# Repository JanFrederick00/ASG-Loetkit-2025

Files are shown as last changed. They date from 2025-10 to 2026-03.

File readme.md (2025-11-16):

# ASG-Loetkit-2025

[Löt-Video](https://www.youtube.com/watch?v=-um5J8tv-0Q)

[Demo-Video](https://www.youtube.com/watch?v=5mWFSo3QfBs)

Dieses Projekt ist eine kleine DMX-leuchte, die 9 LEDs enthält und individuell ansteuern kann.

Es wurde speziell dazu entwickelt, einen Einstieg in das SMD-Löten zu bieten. 
Dazu werden zwei der ICs vorgelötet, der Rest der Komponenten wurden dazu ausgewählt, so einfach wie möglich zu löten zu sein.

## Beschreibung der Schaltung

Das Herzstück des Gerätes ist der CH32V003 Microcontroller. 
Dieser empfängt DMX-Signale entweder von einem USB-Serial chip (FT232RL), oder von einem MAX485-Transciever, der die DMX-Signale übersetzt.
Über einen Schalter kann zwischen den beiden Signalquellen umgeschaltet werden. 

Der Microcontroller liest die gewünschte DMX-Adresse von dem DIP-Schalter aus, und entscheidet basierend auf dem eingestellten Kanal-Modus, welche RGB-Farbwerte die LEDs haben sollen.

Die LEDs sind vom Typ WS2812. Das sind einzeln steuerbare RGB-LEDs die häufig in PCs oder anderen bunt leuchtenden dingen verwendet werden. Alle LEDs werden seriell über einen einzigen Pin am 
Microcontroller angesteuert, und formen eine Kette wo das vorherige LED die Daten an die nächste weitergibt.

Der Microcontroller kann einen kleinen push-schalter auslesen, um durch die Modi durchzuwechseln. Eine kleine rote LED kann dazu verwendet werden um das Vorhandensein eines DMX-Signals zu zeigen.

## Verwendung

### Stromversorgung

Das Gerät wird über den USB-Port mit 5V Strom versorgt. 

### DMX-Signal

Als Signalquelle stehen zwei Möglichkeiten zur Auswahl:

- DMX: Die beiden 3-pin Steckverbinder oben rechts sind die DMX in / out ports. Sie verhalten sich wie die Üblichen 3-pin XLR-buchsen, sind aber kleiner und günstiger. Der Schalter muss dafür in der rechten Stellung sein.
- USB: Wenn der FT232-chip installiert ist, dann kann das Gerät auch an einen Computer direkt angeschlossen werden. Dafür verwenden wir die Software `QLC+`, die diesen Chip nativ unterstützt. Der Schalter muss dafür in der linken Stellung sein.

**Anzeigen des DMX-Signals:**

Wenn der Push-schalter gedrückt ist wärend das Gerät eingesteckt wird, dann blinkt die rote LED D10 kurz, wenn ein neues DMX-Datenpaket empfangen wurde. 

### Auswahl eines Kanal-Moduses

Über einen Klick des Push-schalters wird durch die Kanal-Modi gewechselt. Standardmäßig ist das Gerät im 4-Kanal-Modus. Solange der Knopf gedrückt ist wird ein Muster auf den LEDs gezeigt, der den Modus symbolisiert. 

Die verfügbaren Modi sind wie folgt:

**4-Kanal-Modus**

Klassisches RGB + Dimmer

|Channel|Function|
|---|---|
|1|R|
|2|G|
|3|B|
|4|Dimmer|

**27-Kanal-Modus**

R, G, B für jede der 9 LEDs

|Channel|Function|
|---|---|
|3*n+1|R für Dn|
|3*n+2|G für Dn|
|3*n+3|B für Dn|

(wobei n = 0-8 für die 9 LEDs)

**28-Kanal-Modus**

R, G, B für jede der 9 LEDs, und ein Dimmer der alle gleichzeitig dimmt.

|Channel|Function|
|---|---|
|1|Dimmer|
|3*n+2|R für Dn|
|3*n+3|G für Dn|
|3*n+4|B für Dn|

(wobei n = 0-8 für die 9 LEDs)

**36-Kanal-Modus**

R, G, B und Dimmer für jede der 9 LEDs

|Channel|Function|
|---|---|
|4*n+1|R für Dn|
|4*n+2|G für Dn|
|4*n+3|B für Dn|
|4*n+4|Dimmer für Dn|

**HSV-Modus**

3 Kanäle, die Farbe wird dabei im [HSV-Farbraum](https://de.wikipedia.org/wiki/HSV-Farbraum) eingestellt. Kanal 3 ist dabei Helligkeit, die wie der Dimmer agiert.

|Channel|Function|
|---|---|
|1|Hue (Farbton)|
|2|Saturation (Sättigung)|
|3|Value (Dimmer)|

**3-Kanal-Modus**

Klassisches RGB

|Channel|Function|
|---|---|
|1|R|
|2|G|
|3|B|

### Demo-Modus

Wenn man den Auswahlknopf mehr als 10 sekunden hält, dann wechselt das Gerät in einen eingebauten Demo-Modus.
Alle eingehenden DMX-Signale werden dabei ignoriert.

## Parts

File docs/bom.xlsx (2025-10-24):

Reference | Beschreibung | Wer Lötet? | Link | Kosten/stück | Anzahl | MOQ | Margin | Anzahl benötigt insgesamt | Anzahl (aufgerundet) | Kosten
C1 | Kondensator 100nF 0805 | Freddy | (Stock Freddy) | 0 | 1 | 1 | 0 | 15 | 15 | 0
U1 | Microcontroller CH32V003F4P6 | Freddy | (Stock Freddy) | 0.23 | 1 | 1 | 0 | 15 | 15 | 3.45
U3 | FT232RL | Freddy | (Stock Freddy) | 0 | 1 | 1 | 0 | 15 | 15 | 0
C4, C5, C6, C7, C8, C9, C10, C11, C12, C13, C14, C15 | Kondensator 100nF 1206 | Schüler | https://www.lcsc.com/product-detail/C82601.html | 0.0093 | 12 | 50 | 4 | 240 | 250 | 2.325
U2 | MAX485 | Schüler | https://www.lcsc.com/product-detail/C42428254.html?s_z=n_max485 | 0.0904 | 1 | 5 | 0 | 15 | 15 | 1.356
C2, C3 | Kondensator 22pF 1206 | Schüler | https://www.lcsc.com/product-detail/C377027.html | 0.0087 | 2 | 50 | 1 | 45 | 50 | 0.435
D10 | LED rot 1206 | Schüler | https://www.lcsc.com/product-detail/C3646938.html | 0.0105 | 1 | 50 | 1 | 30 | 50 | 0.525
D1, D2, D3, D4, D5, D6, D7, D8, D9 | RGB-LED WS2812 | Schüler | https://www.lcsc.com/product-detail/C22461793.html?s_z=n_ws2812 | 0.0211 | 9 | 20 | 0 | 135 | 140 | 2.954
Y1 | Quartz 24MHz | Schüler | https://www.lcsc.com/product-detail/C7275046.html | 0.0461 | 1 | 10 | 0 | 15 | 20 | 0.922
C16 | Kondensator Elko THT 220uF 5.0x2.5 | Schüler | (Stock Freddy) | 0 | 1 | 1 | 0 | 15 | 15 | 0
SW1 | Slide Switch DPDT | Schüler | https://www.lcsc.com/product-detail/C22435668.html?s_z=n_dpdt | 0.0372 | 1 | 10 | 0 | 15 | 20 | 0.744
SW2 | DIP-Schalter 9P | Schüler | https://www.lcsc.com/product-detail/C3024975.html | 0.2751 | 1 | 19 | 0 | 15 | 19 | 5.2269
SW3 | Tactile Pushbutton | Schüler | https://www.lcsc.com/product-detail/C42416244.html | 0.0149 | 1 | 50 | 0 | 15 | 50 | 0.745
J1 | USB B | Schüler | https://www.lcsc.com/product-detail/C2962393.html | 0.0861 | 1 | 5 | 0 | 15 | 15 | 1.2915
J2, J3 | JST-XH 3P | Schüler | https://www.lcsc.com/product-detail/C5160912.html | 0.0083 | 2 | 50 | 0 | 30 | 50 | 0.415
 | Platinen | N/A |  | 0.39 | 1 | 20 | 0 | 15 | 20 | 7.8
Anzahl Platinen: |  | 15
 |  |  |  |  |  |  |  |  |  | 28.1894

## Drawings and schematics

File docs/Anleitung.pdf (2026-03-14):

## Gigapixel

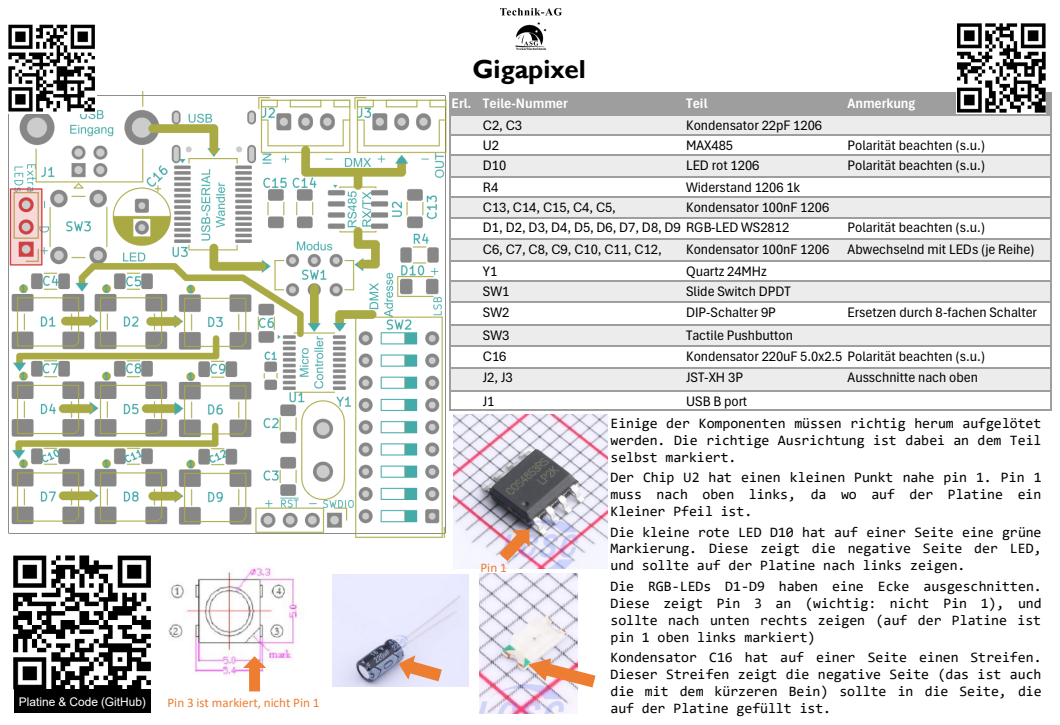
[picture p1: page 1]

Erl. | Teile-Nummer | Teil | Anmerkung
C2, C3 | Kondensator 22pF 1206
U2 | MAX485 | Polarität beachten (s.u.)
D10 | LED rot 1206 | Polarität beachten (s.u.)
R4 | Widerstand 1206 1k
C13, C14, C15, C4, C5, | Kondensator 100nF 1206
D1, D2, D3, D4, D5, D6, D7, D8, D9 RGB-LED WS2812 | | Polarität beachten (s.u.)
C6, C7, C8, C9, C10, C11, C12, | Kondensator 100nF 1206 | Abwechselnd mit LEDs (je Reihe)
Y1 | Quartz 24MHz
SW1 | Slide Switch DPDT
SW2 | DIP-Schalter 9P | Ersetzen durch 8-fachen Schalter
SW3 | Tactile Pushbutton
C16 | Kondensator 220uF 5.0x2.5 Polarität beachten (s.u.)
J2, J3 | JST-XH 3P | Ausschnitte nach oben
J1 | USB B port

Einige der Komponenten müssen richtig herum aufgelötet
werden. Die richtige Ausrichtung ist dabei an dem Teil
selbst markiert.
Der Chip U2 hat einen kleinen Punkt nahe pin 1. Pin 1
muss nach oben links, da wo auf der Platine ein
Kleiner Pfeil ist.
Die kleine rote LED D10 hat auf einer Seite eine grüne
Markierung. Diese zeigt die negative Seite der LED,
und sollte auf der Platine nach links zeigen.
Die RGB-LEDs D1-D9 haben eine Ecke ausgeschnitten.
Diese zeigt Pin 3 an (wichtig: nicht Pin 1), und
sollte nach unten rechts zeigen (auf der Platine ist
pin 1 oben links markiert)
Kondensator C16 hat auf einer Seite einen Streifen.
Dieser Streifen zeigt die negative Seite (das ist auch
die mit dem kürzeren Bein) sollte in die Seite, die

auf der Platine gefüllt ist. Platine & Code (GitHub)

Pin 3 ist markiert, nicht Pin 1

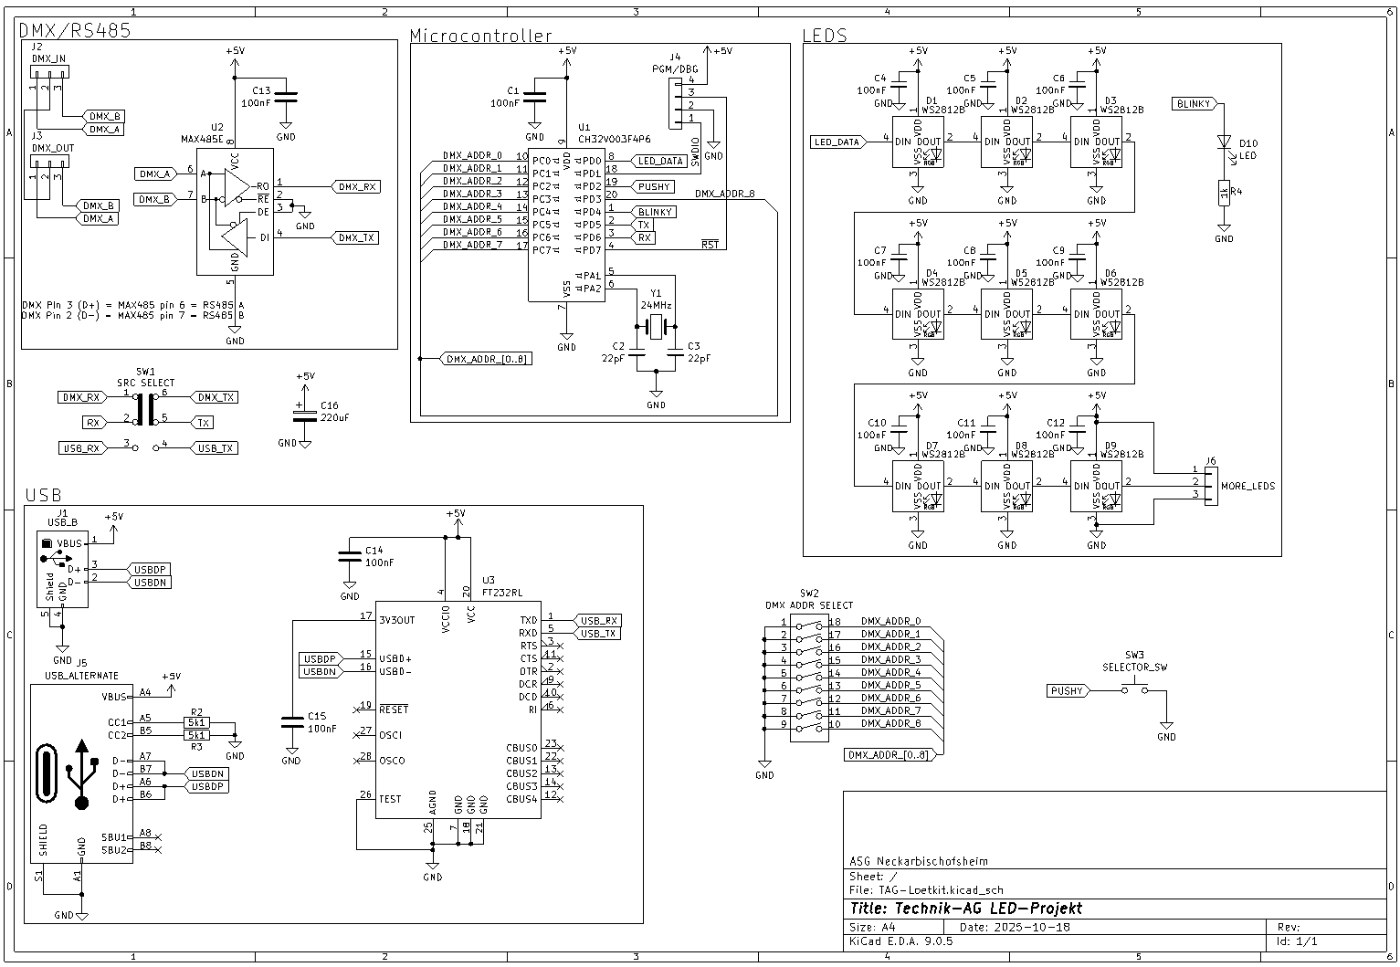
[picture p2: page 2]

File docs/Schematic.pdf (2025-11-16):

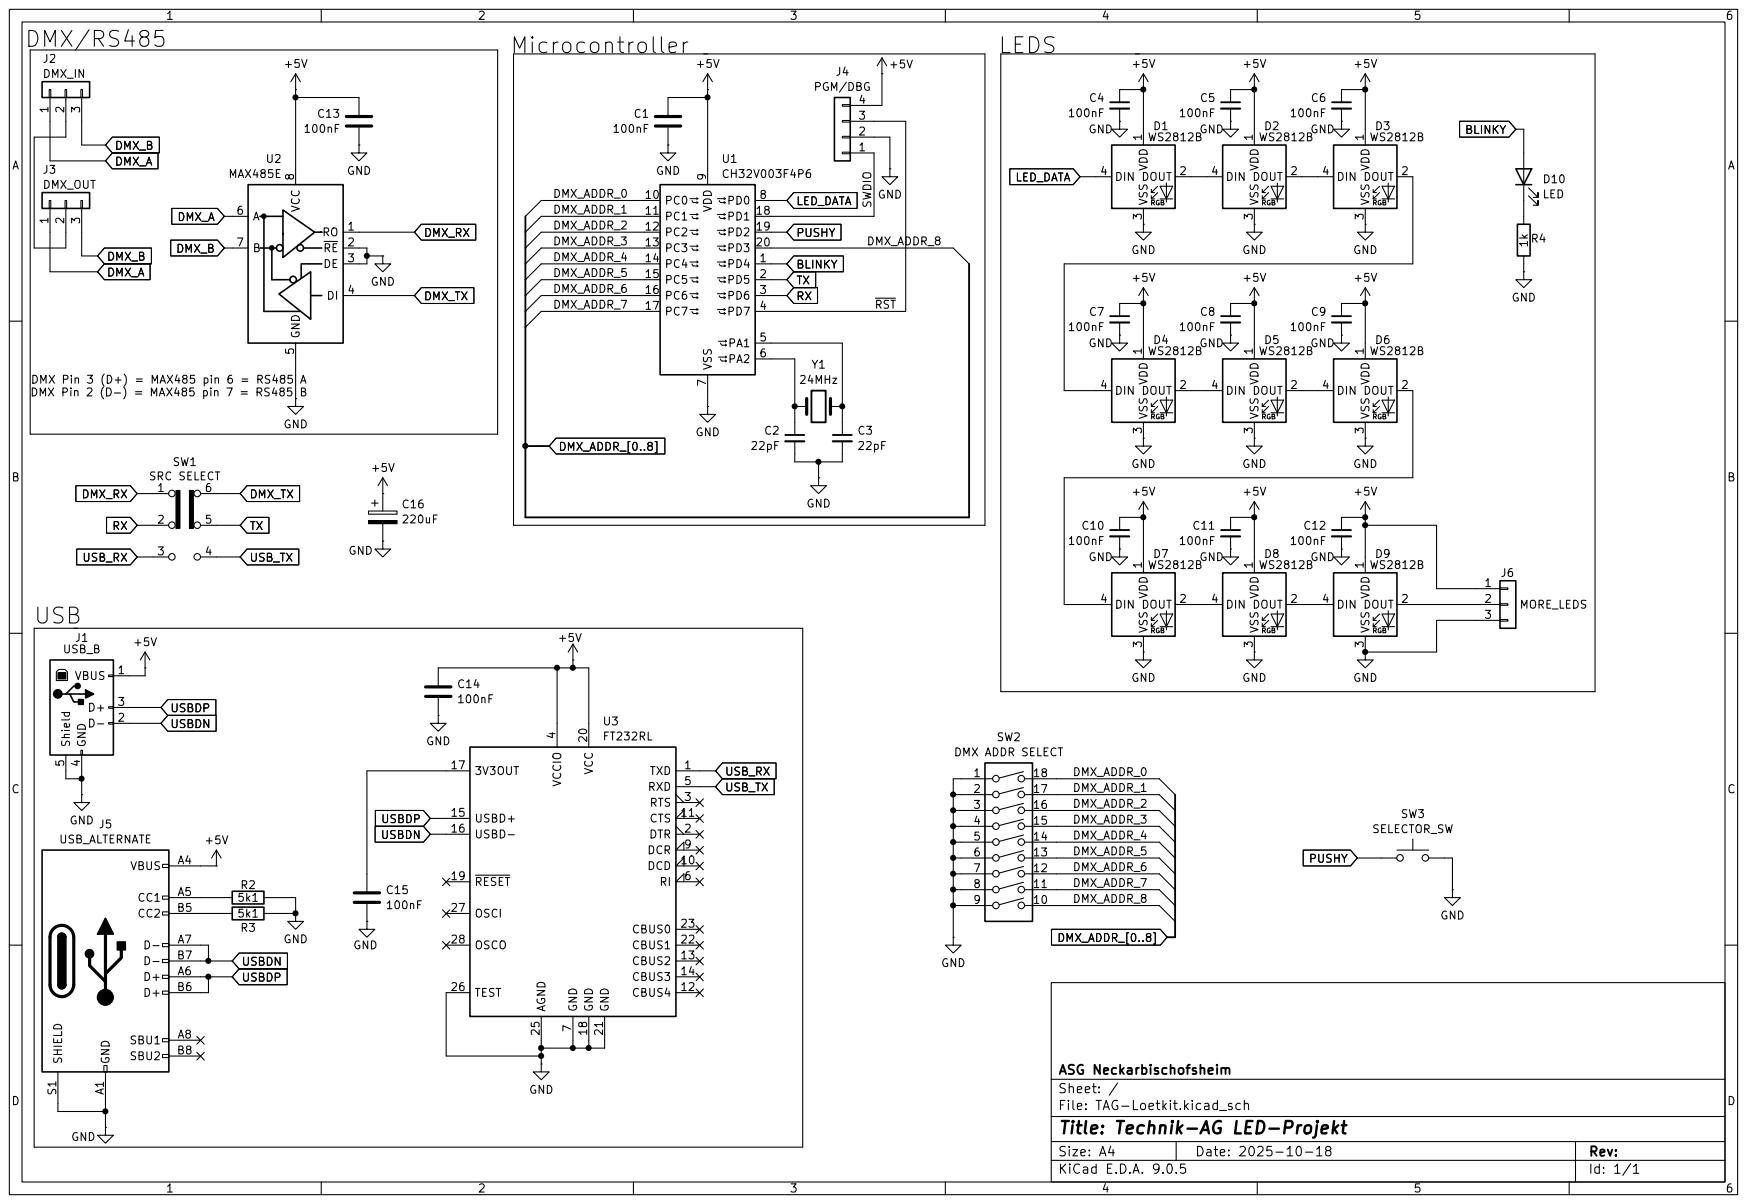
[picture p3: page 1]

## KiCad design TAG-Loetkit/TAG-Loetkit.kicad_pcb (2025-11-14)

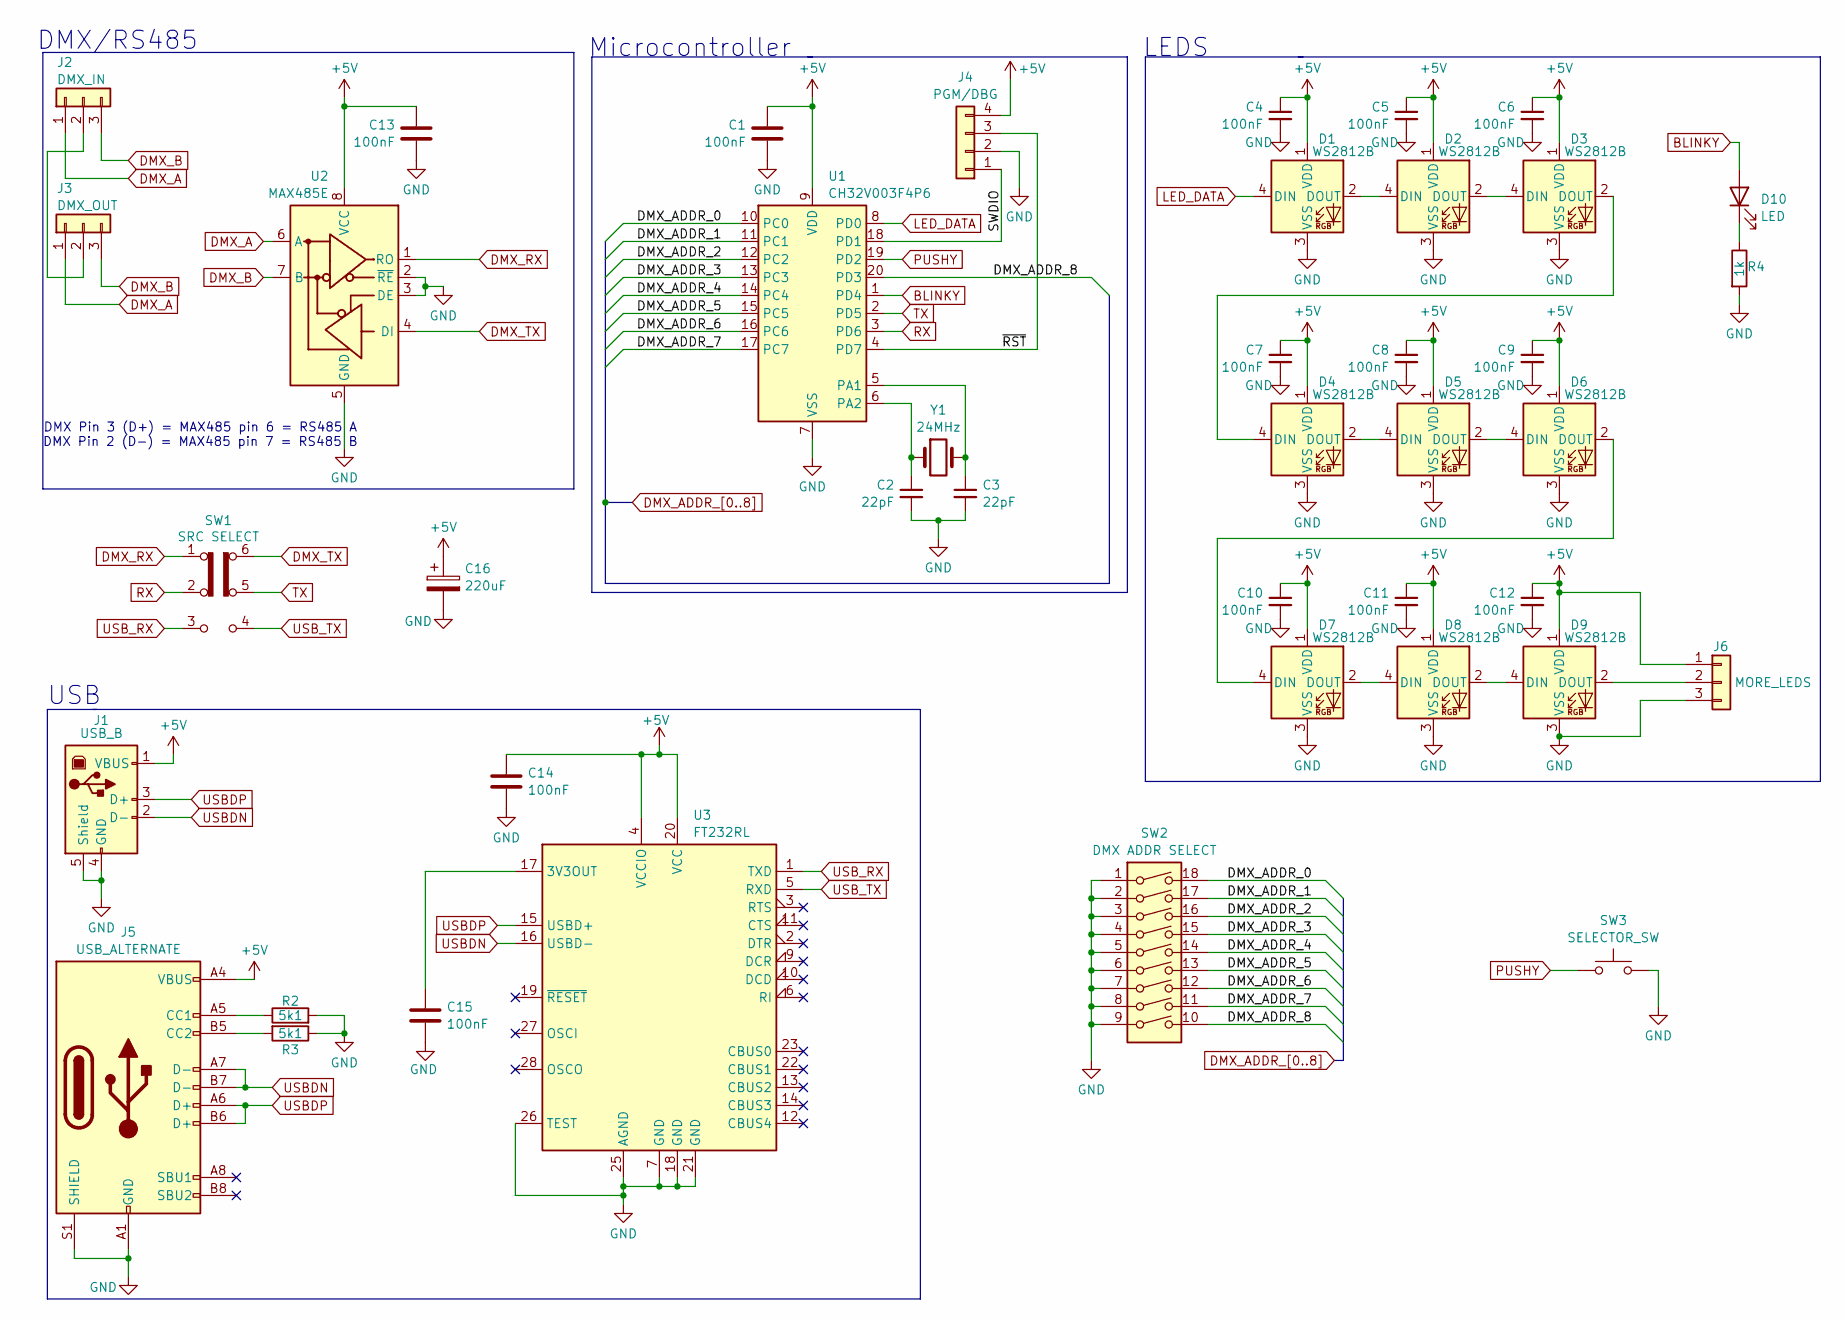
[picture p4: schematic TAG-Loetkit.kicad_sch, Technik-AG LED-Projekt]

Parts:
C1: 100nF; C_0805_2012Metric_Pad1.18x1.45mm_HandSolder
C2, C3: 22pF; C_1206_3216Metric_Pad1.33x1.80mm_HandSolder
C4, C5, C6, C7, C8, C9, C10, C11, C12, C13, C14, C15: 100nF; C_1206_3216Metric_Pad1.33x1.80mm_HandSolder
C16: 220uF; CP_Radial_D6.3mm_P2.50mm
D1, D2, D3, D4, D5, D6, D7, D8, D9: WS2812B; LED_WS2812B_PLCC4_5.0x5.0mm_P3.2mm_XLPads
D10: LED; LED_1206_3216Metric_Pad1.42x1.75mm_HandSolder
J1: USB_B; USB_B_Lumberg_2411_02_Horizontal
J2: DMX_IN; JST_XH_B3B-XH-A_1x03_P2.50mm_Vertical
J3: DMX_OUT; JST_XH_B3B-XH-A_1x03_P2.50mm_Vertical
J4: PGM/DBG; PinHeader_1x04_P2.54mm_Vertical
J5: USB_ALTERNATE; Korean_USBC
J6: MORE_LEDS; PinHeader_1x03_P2.54mm_Vertical
R2, R3: 5k1; R_0805_2012Metric_Pad1.20x1.40mm_HandSolder
R4: 1k; R_1206_3216Metric_Pad1.30x1.75mm_HandSolder
SW1: SRC SELECT; HanElectricDPDTSlideSwitch
SW2: DMX ADDR SELECT; SW_DIP_SPSTx09_Slide_9.78x25.04mm_W7.62mm_P2.54mm
SW3: SELECTOR_SW; SW_PUSH_6mm
U1: CH32V003F4P6; TSSOP-20_4.4x6.5mm_P0.65mm
U2: MAX485E; SOIC-8_3.9x4.9mm_P1.27mm
U3: FT232RL; SSOP-28_5.3x10.2mm_P0.65mm
Y1: 24MHz; Crystal_HC50_Vertical

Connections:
+5V: C1.1, C4.1, C5.1, C6.1, C7.1, C8.1, C9.1, C10.1, C11.1, C12.1, C13.1, C14.1, C16.1, D1.1 (VDD), D2.1 (VDD), D3.1 (VDD), D4.1 (VDD), D5.1 (VDD), D6.1 (VDD), D7.1 (VDD), D8.1 (VDD), D9.1 (VDD), J1.1 (VBUS), J4.4, J5.A4 (VBUS), J5.A9 (VBUS), J5.B4 (VBUS), J5.B9 (VBUS), J6.1, U1.9 (VDD), U2.8 (VCC), U3.4 (VCCIO), U3.20 (VCC)
/SWDIO: J4.1, U1.18 (PD1)
/~RST: J4.3, U1.4 (PD7)
BLINKY: D10.2 (A), U1.1 (PD4)
DMX_A: J2.1, J3.1, U2.6 (A)
DMX_ADDR_0: SW2.18, U1.10 (PC0)
DMX_ADDR_1: SW2.17, U1.11 (PC1)
DMX_ADDR_2: SW2.16, U1.12 (PC2)
DMX_ADDR_3: SW2.15, U1.13 (PC3)
DMX_ADDR_4: SW2.14, U1.14 (PC4)
DMX_ADDR_5: SW2.13, U1.15 (PC5)
DMX_ADDR_6: SW2.12, U1.16 (PC6)
DMX_ADDR_7: SW2.11, U1.17 (PC7)
DMX_ADDR_8: SW2.10, U1.20 (PD3)
DMX_B: J2.3, J3.3, U2.7 (B)
DMX_RX: SW1.1 (A), U2.1 (RO)
DMX_TX: SW1.6 (C), U2.4 (DI)
GND: C1.2, C2.2, C3.2, C4.2, C5.2, C6.2, C7.2, C8.2, C9.2, C10.2, C11.2, C12.2, C13.2, C14.2, C15.2, C16.2, D1.3 (VSS), D2.3 (VSS), D3.3 (VSS), D4.3 (VSS), D5.3 (VSS), D6.3 (VSS), D7.3 (VSS), D8.3 (VSS), D9.3 (VSS), J1.4 (GND), J1.5 (Shield), J4.2, J5.A1 (GND), J5.A12 (GND), J5.B1 (GND), J5.B12 (GND), J5.S1 (SHIELD), J6.3, R2.2, R3.1, R4.2, SW2.1, SW2.2, SW2.3, SW2.4, SW2.5, SW2.6, SW2.7, SW2.8, SW2.9, SW3.2, U1.7 (VSS), U2.2 (~RE), U2.3 (DE), U2.5 (GND), U3.7 (GND), U3.18 (GND), U3.21 (GND), U3.25 (AGND), U3.26 (TEST)
LED_DATA: D1.4 (DIN), U1.8 (PD0)
unnamed: D1.2 (DOUT), D2.4 (DIN)
unnamed: D2.2 (DOUT), D3.4 (DIN)
unnamed: D3.2 (DOUT), D4.4 (DIN)
unnamed: D4.2 (DOUT), D5.4 (DIN)
unnamed: D5.2 (DOUT), D6.4 (DIN)
unnamed: D6.2 (DOUT), D7.4 (DIN)
unnamed: D7.2 (DOUT), D8.4 (DIN)
unnamed: D8.2 (DOUT), D9.4 (DIN)
unnamed: D9.2 (DOUT), J6.2
unnamed: D10.1 (K), R4.1
unnamed: J2.2, J3.2
unnamed: J5.A5 (CC1), R2.1
unnamed: J5.B5 (CC2), R3.2
unnamed: C3.1, U1.5 (PA1), Y1.2
unnamed: C2.1, U1.6 (PA2), Y1.1
unnamed: C15.1, U3.17 (3V3OUT)
PUSHY: SW3.1, U1.19 (PD2)
RX: SW1.2 (B), U1.3 (PD6)
TX: SW1.5 (B), U1.2 (PD5)
USBDN: J1.2 (D-), J5.A7 (D-), J5.B7 (D-), U3.16 (USBD-)
USBDP: J1.3 (D+), J5.A6 (D+), J5.B6 (D+), U3.15 (USBD+)
USB_RX: SW1.3 (C), U3.1 (TXD)
USB_TX: SW1.4 (A), U3.5 (RXD)

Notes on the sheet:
DMX/RS485
LEDS
USB
Microcontroller
DMX Pin 3 (D+) = MAX485 pin 6 = RS485 A DMX Pin 2 (D-) = MAX485 pin 7 = RS485 B

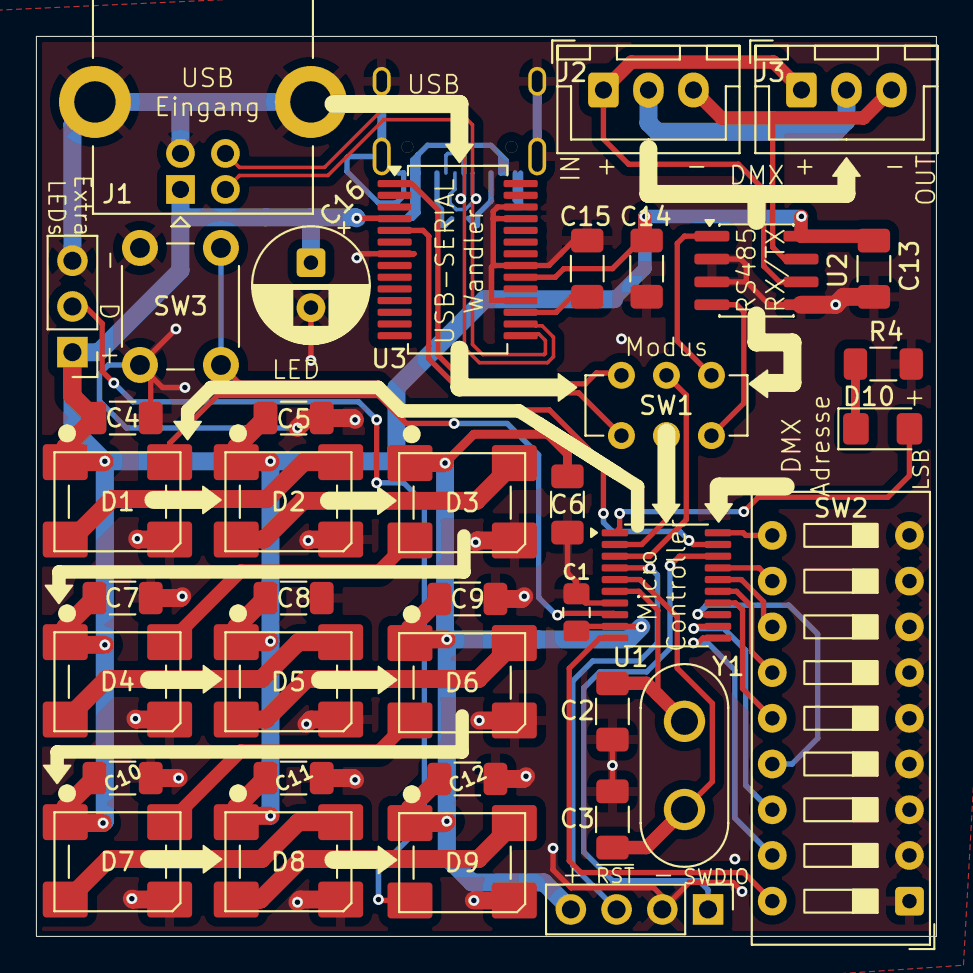
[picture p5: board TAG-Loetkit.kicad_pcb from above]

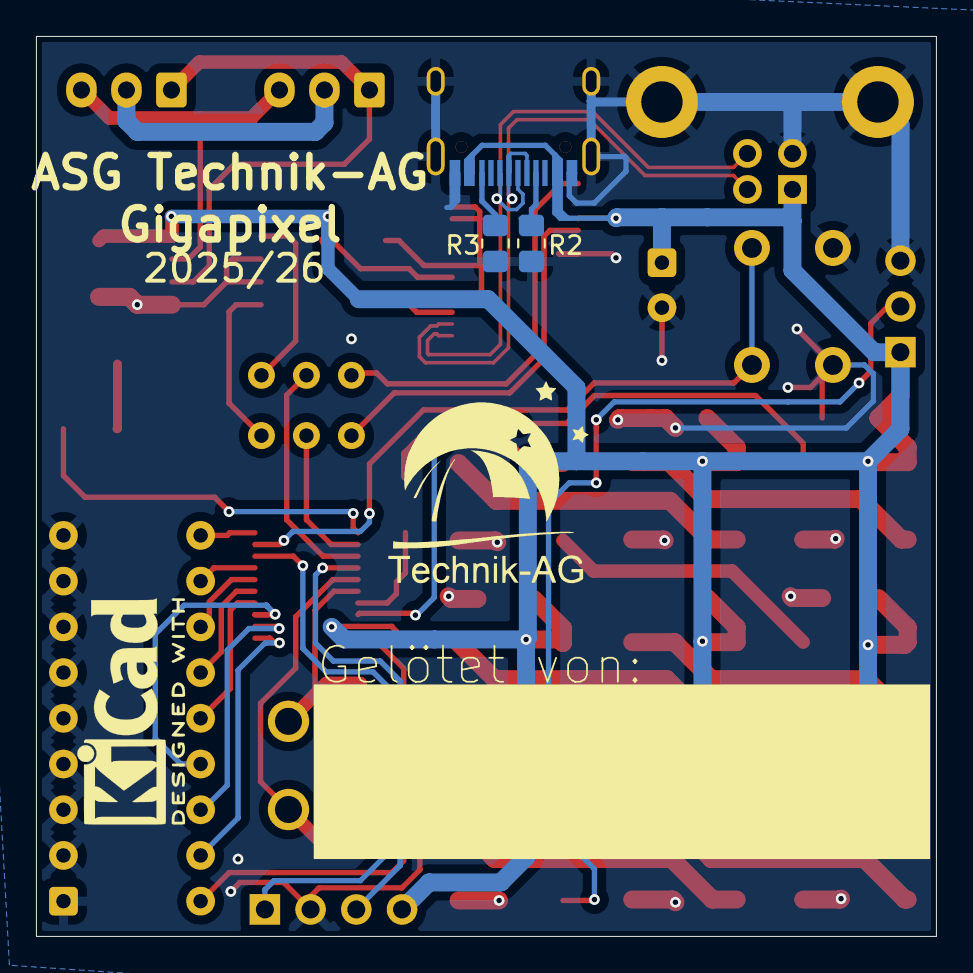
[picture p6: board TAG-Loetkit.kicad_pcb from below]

Board: 2 copper layers, 50.0 x 50.0 mm, 42 parts (3 on the bottom side), 42 nets.

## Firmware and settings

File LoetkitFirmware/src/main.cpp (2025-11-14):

#include <Arduino.h>

#include "pins.h"
#include "ws2812.h"
#include "dmx_ch32v.h"
#include <Button.h>

#define WS2812_COUNT 9

enum class DmxMode : uint8_t
{
  DMX_3CH = 1,
  DMX_4CH = 2,
  DMX_27CH = 3,
  DMX_28CH = 4,
  DMX_36CH = 5,
  DMX_HSV = 6
};

const uint32_t IndicatorLEDOnTime = 20;

Button pushbutton(PIN_PUSHBUTTON);
RGB LEDData[WS2812_COUNT];

DmxMode currentMode = DmxMode::DMX_4CH;   // current DMX mode
bool shows_dmx_mode = false;              // are we currently showing the DMX mode on the main LEDs?
bool led_blink_on_signal_recv = false;    // blink whenever we get a DMX packet
uint64_t led_blink_tmr = 0;               // timer until the red LED should be turned off
bool standaloneMode = false;              // are we in standalone mode?
uint64_t pushbuttonHeldTime = 0;          // since when is the user holding the button?
uint16_t dmx_address = 0x00;              // current DMX address

// blink forever (error condition)
void err_blink(uint32_t ms)
{
  while (1)
  {
    digitalWrite(BUILTIN_LED, HIGH);
    delay(ms / 2);
    digitalWrite(BUILTIN_LED, LOW);
    delay(ms / 2);
  }
}

// read the 9-pin dip switch
uint16_t read_config_bits()
{
  uint16_t value = 0x00;
  for (int i = 0; i < NUM_CONFIG_BITS; ++i)
  {
    if (digitalRead(CONFIG_SWITCH_PINS[i]) == HIGH)
    {
      value |= 1 << i;
    }
  }
  return ~value;
}

// show the current DMX mode on the main LEDs
void IndicateDmxMode()
{
  RGB LEDDataTemp[WS2812_COUNT];

  memset(LEDDataTemp, 0x00, sizeof(RGB) * WS2812_COUNT);

  switch (currentMode)
  {
  case DmxMode::DMX_3CH:
    LEDDataTemp[0] = {255, 0, 0};
    LEDDataTemp[1] = {0, 255, 0};
    LEDDataTemp[2] = {0, 0, 255};
    break;
  case DmxMode::DMX_4CH:
    LEDDataTemp[0] = {255, 0, 0};
    LEDDataTemp[1] = {0, 255, 0};
    LEDDataTemp[2] = {0, 0, 255};
    LEDDataTemp[3] = {255, 255, 255};
    break;
  case DmxMode::DMX_27CH:
    LEDDataTemp[0] = {255, 0, 0};
    LEDDataTemp[1] = {0, 255, 0};
    LEDDataTemp[2] = {0, 0, 255};
    LEDDataTemp[8] = {255, 255, 255};
    break;
  case DmxMode::DMX_28CH:
    LEDDataTemp[0] = {255, 255, 255};
    LEDDataTemp[1] = {255, 0, 0};
    LEDDataTemp[2] = {0, 255, 0};
    LEDDataTemp[3] = {0, 0, 255};
    LEDDataTemp[8] = {255, 255, 255};
    break;
  case DmxMode::DMX_36CH:
    LEDDataTemp[0] = {255, 0, 0};
    LEDDataTemp[1] = {0, 255, 0};
    LEDDataTemp[2] = {0, 0, 255};
    LEDDataTemp[3] = {255, 255, 255};
    LEDDataTemp[7] = {255, 255, 255};
    LEDDataTemp[8] = {255, 255, 255};
    break;
  case DmxMode::DMX_HSV:
    LEDDataTemp[0] = {255, 0, 0};
    LEDDataTemp[1] = {255, 255, 255};
    LEDDataTemp[2] = {16, 16, 16};
    break;
  }

  ws2812_writeMultiple(LEDDataTemp, WS2812_COUNT);
}

// Write the LED data to the LEDs
inline void WriteLEDs()
{
  ws2812_writeMultiple(LEDData, WS2812_COUNT);
}

void setup()
{
  // Init GPIO
  ws2812_init();
  pinMode(PIN_PUSHBUTTON, INPUT_PULLUP);
  pinMode(BUILTIN_LED, OUTPUT);
  for (int i = 0; i < NUM_CONFIG_BITS; ++i)
    pinMode(CONFIG_SWITCH_PINS[i], INPUT_PULLUP);

  // Read CPU Frequency and enter error mode on wrong frequency.
  SystemCoreClockUpdate();
  if (SystemCoreClock != 48000000)
    err_blink(500); // Wrong frequency -> blink forever.

  // begin DMX receiving
  dmx_beginRX();

  // reset all LEDs to Black (off)
  memset(LEDData, 0x00, sizeof(RGB) * WS2812_COUNT);

  // if the button is held on startup, show DMX data with the red LED
  if (pushbutton.read() == Button::PRESSED) led_blink_on_signal_recv = true; 

  // show the current DMX mode on startup
  digitalWrite(BUILTIN_LED, HIGH);
  IndicateDmxMode();
  delay(500);
  digitalWrite(BUILTIN_LED, LOW);

  // LEDs off, waiting for Data.
  WriteLEDs();
}

void loop()
{
  if (standaloneMode)
  {
    uint16_t time_offset = (millis() % 3600) / 10;

    for (int y = 0; y < 3; ++y)
    {
      for (int x = 0; x < 3; ++x)
      {
        auto index = y * 3 + x;
        LEDData[index] = RGB_From_Hsv(
            time_offset + (10 * x) + (10 * y),
            StandaloneModeSaturationLookup[index % 9],
            StandaloneModeValueLookup[index % 9]);
      }
    }

    WriteLEDs();
  }
  else
  {
    // DMX address is one lower than the value selected (so the first address corresponds to setting 0x01)
    dmx_address = (read_config_bits() - 1) & 0x1FF;

    // new DMX data -> set LEDs
    if (dmx_newPacket() == 0xFF)
    {
      if (led_blink_on_signal_recv)
      {
        led_blink_tmr = millis() + IndicatorLEDOnTime;
        digitalWrite(BUILTIN_LED, HIGH);
      }

      switch (currentMode)
      {
      case DmxMode::DMX_28CH:
      {
        unsigned char buffer[WS2812_COUNT * 3 + 1];
        dmx_getValues(dmx_address, buffer, sizeof(buffer));

        for (int i = 0; i < WS2812_COUNT; ++i)
        {
          LEDData[i].R = ScaleUnorm(buffer[1 + (3 * i) + 0], buffer[0]);
          LEDData[i].G = ScaleUnorm(buffer[1 + (3 * i) + 1], buffer[0]);
          LEDData[i].B = ScaleUnorm(buffer[1 + (3 * i) + 2], buffer[0]);
        }
      }
      break;
      case DmxMode::DMX_27CH:
      {
        dmx_getValues(dmx_address, (unsigned char *)LEDData, 3 * WS2812_COUNT);
      }
      break;
      case DmxMode::DMX_36CH:
      {
        unsigned char buffer[WS2812_COUNT * 4];
        dmx_getValues(dmx_address, buffer, sizeof(buffer));
        for (int i = 0; i < WS2812_COUNT; ++i)
        {
          LEDData[i].R = ScaleUnorm(buffer[(4 * i) + 0], buffer[(4 * i) + 3]);
          LEDData[i].G = ScaleUnorm(buffer[(4 * i) + 1], buffer[(4 * i) + 3]);
          LEDData[i].B = ScaleUnorm(buffer[(4 * i) + 2], buffer[(4 * i) + 3]);
        }
      }
      break;
      case DmxMode::DMX_3CH:
      {
        unsigned char buffer[3];
        dmx_getValues(dmx_address, buffer, sizeof(buffer));
        for (int i = 0; i < WS2812_COUNT; ++i)
        {
          LEDData[i].R = buffer[0];
          LEDData[i].G = buffer[1];
          LEDData[i].B = buffer[2];
        }
      }
      break;
      case DmxMode::DMX_4CH:
      {
        unsigned char buffer[4];
        dmx_getValues(dmx_address, buffer, sizeof(buffer));

        buffer[0] = ScaleUnorm(buffer[0], buffer[3]);
        buffer[1] = ScaleUnorm(buffer[1], buffer[3]);
        buffer[2] = ScaleUnorm(buffer[2], buffer[3]);

        for (int i = 0; i < WS2812_COUNT; ++i)
        {
          LEDData[i].R = buffer[0];
          LEDData[i].G = buffer[1];
          LEDData[i].B = buffer[2];
        }
      }
      break;
      case DmxMode::DMX_HSV:
      {
        unsigned char buffer[3];
        dmx_getValues(dmx_address, buffer, sizeof(buffer));
        float fHue = (buffer[0] / 255.0f) * 360.0f;

        RGB color = RGB_From_Hsv((uint16_t)fHue, buffer[1], buffer[2]);
        for (int i = 0; i < WS2812_COUNT; ++i)
        {
          LEDData[i] = color;
        }
      }
      break;
      }

      if (!shows_dmx_mode)
        WriteLEDs();
    }
  }

  // if the button is pressed, cycle through channel modes
  if (pushbutton.pressed())
  {
    // next channel mode
    currentMode = (DmxMode)((uint8_t)currentMode + 1);
    if ((int)currentMode > (int)DmxMode::DMX_HSV)
      currentMode = DmxMode::DMX_3CH;

    IndicateDmxMode();
    shows_dmx_mode = true;
    pushbuttonHeldTime = millis();
  }
  else if (pushbutton.released())
  {
    // only resume showing the DMX data after pushbutton was released.
    shows_dmx_mode = false;
    WriteLEDs();
  }
  else if (pushbutton.read() == Button::PRESSED)
  {
    if ((millis() - pushbuttonHeldTime) > 10000)
    {
      standaloneMode = !standaloneMode;
    }
  }

  if (led_blink_tmr > 0 && millis() > led_blink_tmr)
  {
    led_blink_tmr = 0;
    digitalWrite(BUILTIN_LED, LOW);
  }
}

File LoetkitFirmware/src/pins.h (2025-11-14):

#pragma once
#include <Arduino.h>

const uint8_t BUILTIN_LED = PD4;
const uint8_t PIN_PUSHBUTTON = PD2;
const uint8_t NUM_CONFIG_BITS = 9;
const uint8_t CONFIG_SWITCH_PINS[NUM_CONFIG_BITS] = {PD3, PC7, PC6, PC5, PC4, PC3, PC2, PC1, PC0}; // LSB first

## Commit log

2025-10-24 erste Version
    [TAG-Loetkit.kicad_pcb, TAG-Loetkit.kicad_sch, bom.xlsx]
2025-11-14 Firmware finalisiert
    [TAG-Loetkit-B_Cu.gbr, TAG-Loetkit-B_Mask.gbr, TAG-Loetkit-B_Paste.gbr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]
